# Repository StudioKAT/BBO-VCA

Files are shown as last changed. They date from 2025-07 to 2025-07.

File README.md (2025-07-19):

# BBO&VCA
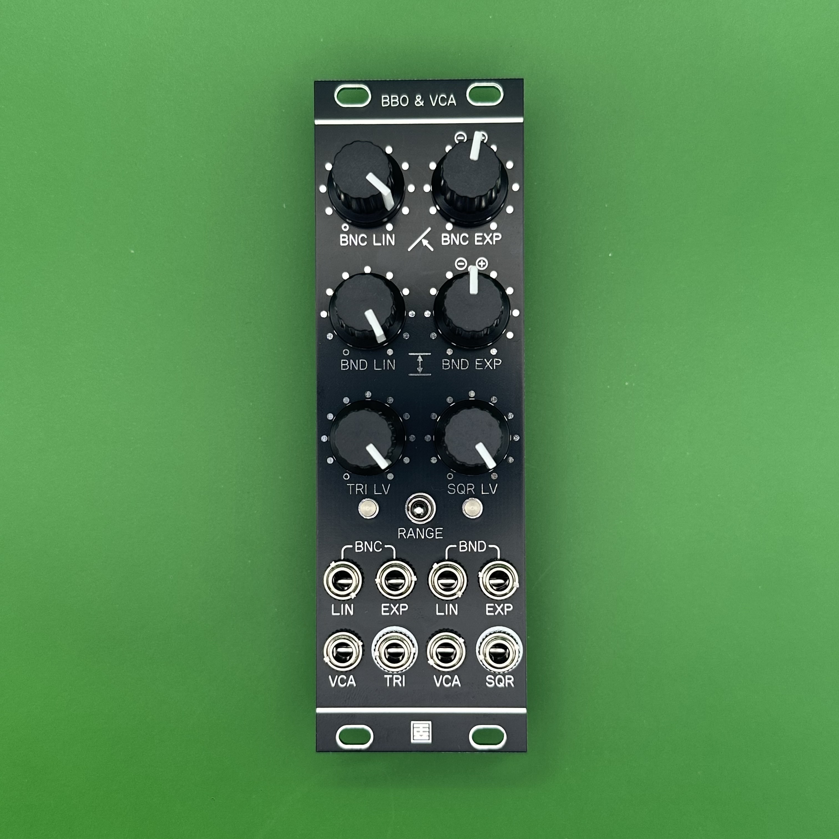
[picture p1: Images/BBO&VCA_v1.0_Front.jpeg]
BBO&VCA_Front


## 概要 / Overview

**BBO&VCA** は、Ieaskul F. Mobenthey の Denum と [crucFX Utility BBO](https://github.com/d42kn355/BoundsBounceOscillator) にインスパイアされた「バウンズ・バウンス・オシレーター（Bounds Bounce Oscillator）」です。  
この回路は、「バウンス（Bounce）」と「バウンズ（Bounds）」という、2つの概念を軸に動作します。  
ボールが2つの壁の間を行き来して跳ねている様子をイメージしてください。バウンスはボールのスピード、バウンズはその2つの壁の距離です。  
このオシレーターでは、バウンスを大きくすると周波数が上がり、バウンズを狭めると振幅が下がる代わりに周波数はさらに上がります。つまり、壁を近づけると、ボール（信号）の移動が速くなるという構造です。  
**BBO&VCA** は、バウンスとバウンズをそれぞれ独立して調整・変調でき、主出力からは常に三角波が出力されます。また、もう1つの出力からは矩形波が得られます。  
さらに、レンジスイッチにより3つの動作範囲を選択できます：
- 標準オーディオレート
- 低オーディオレート
- LFOレート

出力される三角波と矩形波は、それぞれ専用のリニアVCAを通して出力されており、外部CVやノブで音量（振幅）をコントロールできます。  
> ※ 1V/oct の標準CVピッチ制御には対応していません。

**BBO&VCA** is a "Bounds Bounce Oscillator" inspired by Ieaskul F. Mobenthey's *Denum* and the [crucFX Utility BBO](https://github.com/d42kn355/BoundsBounceOscillator).  
This circuit operates based on two key concepts: **Bounce** and **Bounds**.  
Imagine a ball bouncing back and forth between two walls. The **Bounce** represents the speed of the ball, and the **Bounds** represent the distance between the two walls.  

In this oscillator, increasing the Bounce raises the frequency. Narrowing the Bounds further increases the frequency but reduces the amplitude.  
In other words, when the walls are brought closer together, the ball (i.e., the signal) travels faster, resulting in a higher pitch.

**BBO&VCA** allows independent control and modulation of both Bounce and Bounds.  
The main output always produces a triangle wave, while the secondary output provides a square wave.  

A range switch allows you to select from three operating ranges:
- Standard audio rate  
- Low audio rate  
- LFO rate  

Both the triangle and square waves are routed through dedicated linear VCAs, allowing you to control their amplitude (volume) via knobs or external CV.

> *Note: This module does not support standard 1V/oct pitch tracking.*

## 仕様 / Spec
- Format: Eurorack
- Function: Oscillator / LFO
- Current needs: +12V: 30mA, -12V: 30mA
- Width: 8 HP
- Depth: 25mm (including power connector)

## 販売 / Sales

StudioKATオフィシャルショップで販売しています。(日本国内限定)  
 https://www.studiokat.jp/items/113562094

## ライセンス / License

この作品は [Creative Commons 表示 - 継承 4.0 国際 (CC BY-SA 4.0)](https://creativecommons.org/licenses/by-sa/4.0/deed.ja) の下でライセンスされています。  
This work is licensed under the [Creative Commons Attribution-ShareAlike 4.0 International License](https://creativecommons.org/licenses/by-sa/4.0/).

## クレジット / Credits

- Designed by : StudioKAT
- Website : https://www.studiokat.jp/
- GitHub : https://github.com/StudioKAT
- X(Twitter) : https://x.com/StudioKAT_synth
- Instagram : https://www.instagram.com/studiokat_modular/

## 更新履歴 / Changelog

- `2025-07-17` Released version 1.0

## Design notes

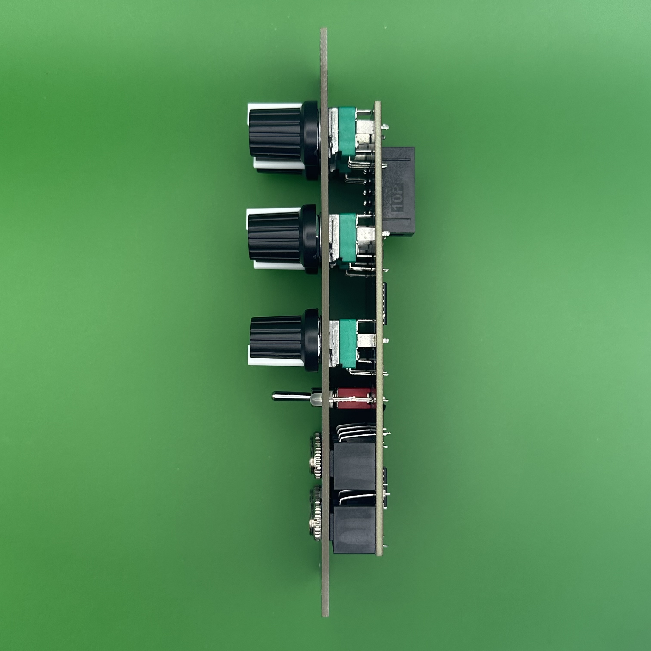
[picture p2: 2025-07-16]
Images/BBO&VCA_v1.0_Side.jpeg

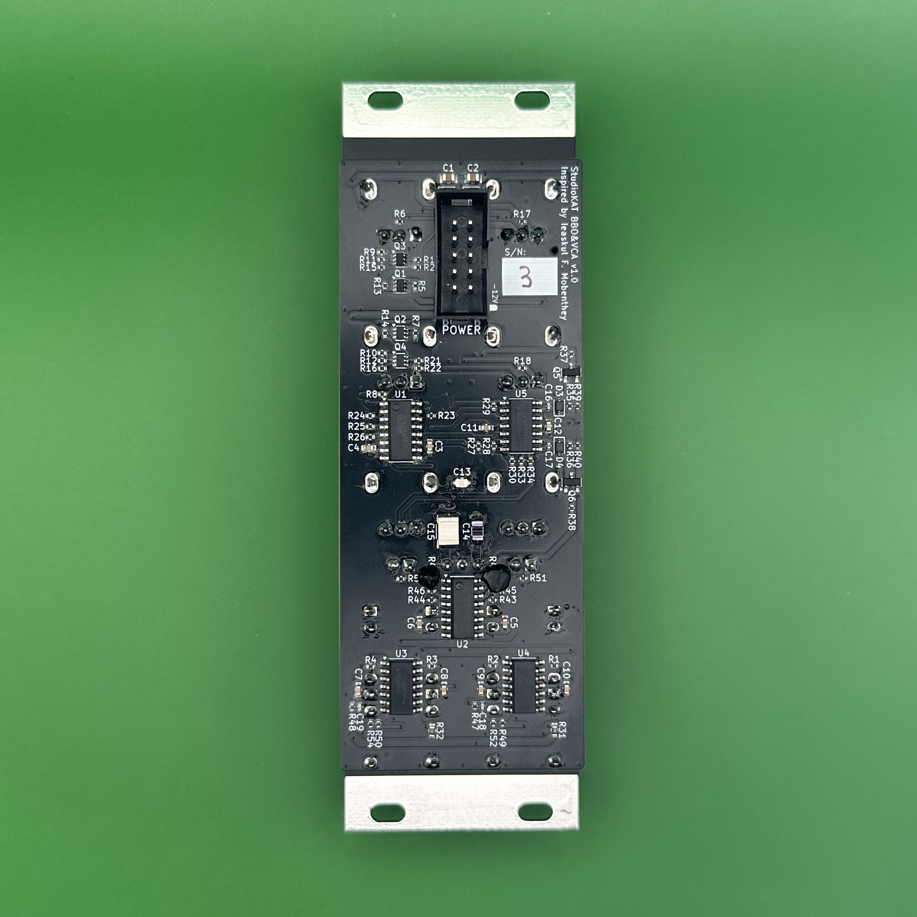
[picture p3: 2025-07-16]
Images/BBO&VCA_v1.0_Back.jpeg

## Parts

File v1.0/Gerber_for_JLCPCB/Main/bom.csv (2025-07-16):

Designator | Footprint | Quantity | Value | LCSC Part #
C1, C2 | 0805 | 2 | 22uF | C45783
C10, C11, C12, C3, C4, C5, C6, C7, C8, C9 | 0603 | 10 | 100nF | C14663
C13 | 0805 | 1 | 1nF
C14 | 1206 | 1 | 1uF
C15 | 1913 | 1 | 47nF
C16, C17 | 0402 | 2 | 330pF | C13533
C18, C19 | 0402 | 2 | 47pF | C1567
D1, D2 | D_SOD-323 | 2 | 1N5819WS | C64886
D3, D4 | D_SOD-323 | 2 | 1N4148WS | C2128
D5, D6 | LED_D3.0mm | 2 | LED_Dual_Bidirectional
J1 | BoxHeader_2x05_2.54mm_Europower_2 | 1 | POWER
J2 | AudioJack_PJ301M-12 | 1 | Bounce_Lin
J3 | AudioJack_PJ301M-12 | 1 | Bounce_CV
J4 | AudioJack_PJ301M-12 | 1 | Bounds_Lin
J5 | AudioJack_PJ301M-12 | 1 | Bounds_CV
J6 | AudioJack_PJ301M-12 | 1 | VCA_CV_Triangle
J7 | AudioJack_PJ301M-12 | 1 | VCA_CV_Square
J8 | AudioJack_PJ301M-12 | 1 | Triangle_OUT
J9 | AudioJack_PJ301M-12 | 1 | Square_OUT
Q1, Q2, Q3, Q4 | SOT-363_SC-70-6 | 4 | BCM857BS | C20426291
Q5, Q6 | SOT-23 | 2 | MMBT3906 | C7420354
R1, R2, R3, R4 | 0402 | 4 | 10M | C26082
R10, R19, R21, R6, R8, R9 | 0402 | 6 | 100K | C25741
R11, R12, R20, R22, R26, R29, R30, R49, R50 | 0402 | 9 | 10K | C25744
R13, R14, R15, R16, R51, R53 | 0402 | 6 | 4.7K | C25900
R17, R18, R24, R25 | 0402 | 4 | 47K | C25792
R23 | 0402 | 1 | 470K | C25790
R27, R28, R5, R7 | 0402 | 4 | 22K | C25768
R31, R32 | 0603 | 2 | 15K | C22809
R33, R34 | 0402 | 2 | 330K | C25778
R35, R36 | 0402 | 2 | 33K | C25779
R37, R38 | 0402 | 2 | 6.8K | C25917
R39, R40, R52, R54 | 0402 | 4 | 1K | C11702
R41 | 0603 | 1 | 240K | C4197
R42 | 0603 | 1 | 360K | C23146
R43, R44, R45, R46 | 0402 | 4 | 680R | C25130
R47, R48 | 0402 | 2 | 18K | C25762
RV1, RV2, RV3, RV4 | Potentiometer_RV09 | 4 | B50K
RV5, RV6 | Potentiometer_RV09 | 2 | B100K
SW1 | ToggleSwitch_2MS1-T2-B4-M2-Q-E-S | 1 | SW_SPDT_MSM
U1, U2 | SOIC-16_3.9x9.9mm_P1.27mm | 2 | LM13700 | C174050
U3, U4, U5 | SOIC-14_3.9x8.7mm_P1.27mm | 3 | TL074 | C12594

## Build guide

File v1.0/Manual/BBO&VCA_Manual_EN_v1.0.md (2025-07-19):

# BBO&VCA Manual (EN)
BBO&VCA_Front

## Overview

**BBO&VCA** is a "Bounds Bounce Oscillator" inspired by Ieaskul F. Mobenthey’s *Denum* and the [crucFX Utility BBO](https://github.com/d42kn355/BoundsBounceOscillator).  
This oscillator is based on two key concepts: **Bounce** and **Bounds**.  
Imagine a ball bouncing back and forth between two walls. The **Bounce** represents the speed of the ball, and the **Bounds** represent the distance between the walls.  
In this oscillator, increasing the Bounce raises the frequency, while narrowing the Bounds increases the frequency further but reduces the amplitude. In other words, bringing the walls closer causes the ball (signal) to move faster.

**BBO&VCA** allows you to independently adjust and modulate both Bounce and Bounds. The main output always provides a triangle wave, while a secondary output provides a square wave.  
A range switch offers three operating modes:
- Standard audio rate  
- Low audio rate  
- LFO rate

Both the triangle and square waves are passed through dedicated linear VCAs, allowing their amplitude (volume) to be controlled via knobs or external CV.

## Specifications

- **Format**: Eurorack  
- **Width**: 8 HP  
- **Depth**: 25 mm  
- **Current Consumption**: +12V: 30mA / -12V: 30mA  

> **IMPORTANT**: Connect the ribbon cable so that the red stripe aligns with -12V.  
> Incorrect connection may damage the module.  
> **Always check cable orientation before powering on.**

## Functions of Each Section
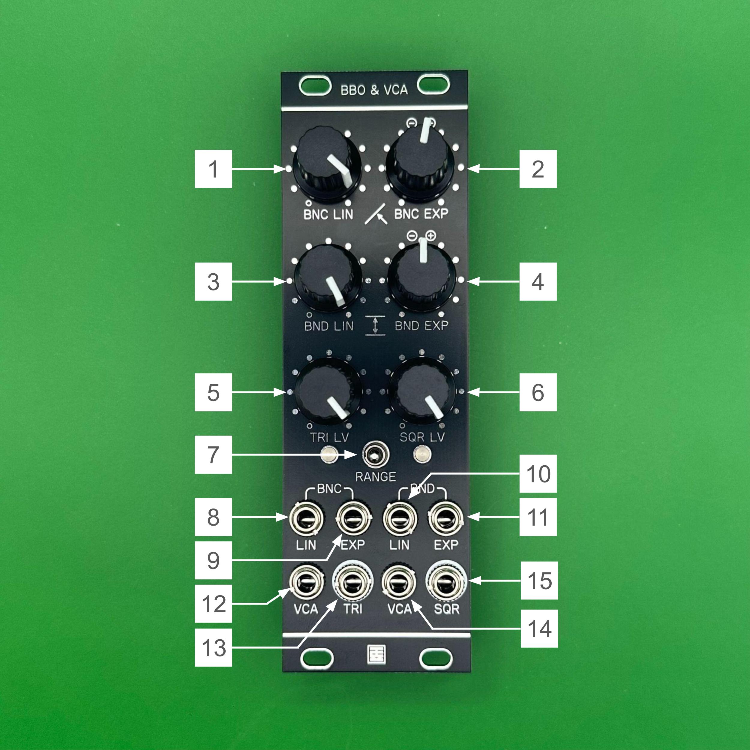
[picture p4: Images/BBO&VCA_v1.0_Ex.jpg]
BBO&VCA_Explanation


1. **BNC LIN**  
   Sets the base position and speed (rate) for Bounce.

2. **BNC EXP**  
   Attenuverter for the CV signal connected to BNC EXP IN. At the center position, modulation is off. Turning clockwise applies modulation with positive polarity, and counterclockwise applies it with inverted polarity.

3. **BND LIN**  
   Sets the base position and speed (rate) for Bounds.

4. **BND EXP**  
   Attenuverter for the CV signal connected to BND EXP IN. At the center position, modulation is off. Turning clockwise applies modulation with positive polarity, and counterclockwise applies it with inverted polarity.

5. **TRI LV**  
   Adjusts the amplitude (volume) of the triangle wave.

6. **SQR LV**  
   Adjusts the amplitude (volume) of the square wave.

7. **RANGE**  
   Switch to select oscillator range. Three options available:  
   - Standard audio rate  
   - Low audio rate  
   - LFO rate

8. **BNC LIN IN**  
   Linear CV input for Bounce.

9. **BNC EXP IN**  
   Exponential CV input for Bounce.

10. **BND LIN IN**  
   Linear CV input for Bounds.

11. **BND EXP IN**  
   Exponential CV input for Bounds.

12. **TRI VCA IN**  
   CV input for triangle wave amplitude control.

13. **TRI OUT**  
   Triangle wave output.

14. **SQR VCA IN**  
   CV input for square wave amplitude control.

15. **SQR OUT**  
   Square wave output.

> *This module does not support standard 1V/oct pitch tracking.*

## License

This work is licensed under the [Creative Commons Attribution-ShareAlike 4.0 International (CC BY-SA 4.0)](https://creativecommons.org/licenses/by-sa/4.0/deed.en).

## Credits

- **Designed by**: StudioKAT  
- **Website**: [https://www.studiokat.jp/](https://www.studiokat.jp/)  
- **GitHub**: [https://github.com/StudioKAT](https://github.com/StudioKAT)  
- **X (formerly Twitter)**: [https://x.com/StudioKAT_synth](https://x.com/StudioKAT_synth)  
- **Instagram**: [https://www.instagram.com/studiokat_modular/](https://www.instagram.com/studiokat_modular/)

## Revision History

- `2025-07-17`: v1.0 Release

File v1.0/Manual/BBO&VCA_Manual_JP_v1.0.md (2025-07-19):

# BBO&VCA マニュアル（日本語）
BBO&VCA_Front

## 概要

**BBO&VCA** は、Ieaskul F. Mobenthey の Denum と [crucFX Utility BBO](https://github.com/d42kn355/BoundsBounceOscillator) にインスパイアされた「バウンズ・バウンス・オシレーター（Bounds Bounce Oscillator）」です。  
この回路は、「バウンス（Bounce）」と「バウンズ（Bounds）」という、2つの概念を軸に動作します。  
ボールが2つの壁の間を行き来して跳ねている様子をイメージしてください。バウンスはボールのスピード、バウンズはその2つの壁の距離です。  
このオシレーターでは、バウンスを大きくすると周波数が上がり、バウンズを狭めると振幅が下がる代わりに周波数はさらに上がります。つまり、壁を近づけると、ボール（信号）の移動が速くなるという構造です。  
**BBO&VCA** は、バウンスとバウンズをそれぞれ独立して調整・変調でき、主出力からは常に三角波が出力されます。また、もう1つの出力からは矩形波が得られます。  
さらに、レンジスイッチにより3つの動作範囲を選択できます：
- 標準オーディオレート
- 低オーディオレート
- LFOレート

出力される三角波と矩形波は、それぞれ専用のリニアVCAを通して出力されており、外部CVやノブで音量（振幅）をコントロールできます。  

## 仕様

- **フォーマット**：Eurorack  
- **幅**：8 HP  
- **奥行き**：25 mm  
- **消費電流**：+12V: 30mA / -12V: 30mA  

> ※ ケーブルの赤いラインが -12V に接続されるようにしてください。  
> 誤って接続すると、モジュールが故障する可能性があります。  
> **電源投入前にケーブルの向きを必ず確認してください。**

## 各部の機能
BBO&VCA_Explanation

1. **BNC LIN**  
   バウンス（Bounce）の基準位置や速度（レート）を設定するノブです。

2. **BNC EXP**  
   BNC EXP IN に接続されたCV信号の影響度を調整するアッテヌバーターです。ノブ中央で無効、時計回りで正極性、反時計回りで逆極性のモジュレーションが適用されます。

3. **BND LIN**  
   バウンズ（Bounds）の基準位置や速度（レート）を設定するノブです。

4. **BND EXP**  
   BND EXP IN に接続されたCV信号の影響度を調整するアッテヌバーターです。ノブ中央で無効、時計回りで正極性、反時計回りで逆極性のモジュレーションが適用されます。

5. **TRI LV**  
   三角波の音量（振幅）を調整するノブです。

6. **SQR LV**  
   矩形波の音量（振幅）を調整するノブです。

7. **RANGE**  
   発振レンジを切り替えるスイッチです。以下の3段階があります：  
   - 標準オーディオレート  
   - 低オーディオレート  
   - LFOレート

8. **BNC LIN IN**  
   バウンス（Bounce）のリニアCV入力です。

9. **BNC EXP IN**  
   バウンス（Bounce）のエクスポネンシャルCV入力です。

10. **BND LIN IN**  
   バウンズ（Bounds）のリニアCV入力です。

11. **BND EXP IN**  
   バウンズ（Bounds）のエクスポネンシャルCV入力です。

12. **TRI VCA IN**  
   三角波の音量を制御するためのCV入力です。

13. **TRI OUT**  
   三角波の出力端子です。

14. **SQR VCA IN**  
   矩形波の音量を制御するためのCV入力です。

15. **SQR OUT**  
   矩形波の出力端子です。

> ※ 本モジュールは 1V/oct の標準CVピッチ制御には対応していません。

## ライセンス

この作品は [Creative Commons 表示 - 継承 4.0 国際 (CC BY-SA 4.0)](https://creativecommons.org/licenses/by-sa/4.0/deed.ja) の下でライセンスされています。

## クレジット

- **Designed by**：StudioKAT  
- **Website**：[https://www.studiokat.jp/](https://www.studiokat.jp/)  
- **GitHub**：[https://github.com/StudioKAT](https://github.com/StudioKAT)  
- **X（旧Twitter）**：[https://x.com/StudioKAT_synth](https://x.com/StudioKAT_synth)  
- **Instagram**：[https://www.instagram.com/studiokat_modular/](https://www.instagram.com/studiokat_modular/)

## 更新履歴

- `2025-07-17`：v1.0 リリース

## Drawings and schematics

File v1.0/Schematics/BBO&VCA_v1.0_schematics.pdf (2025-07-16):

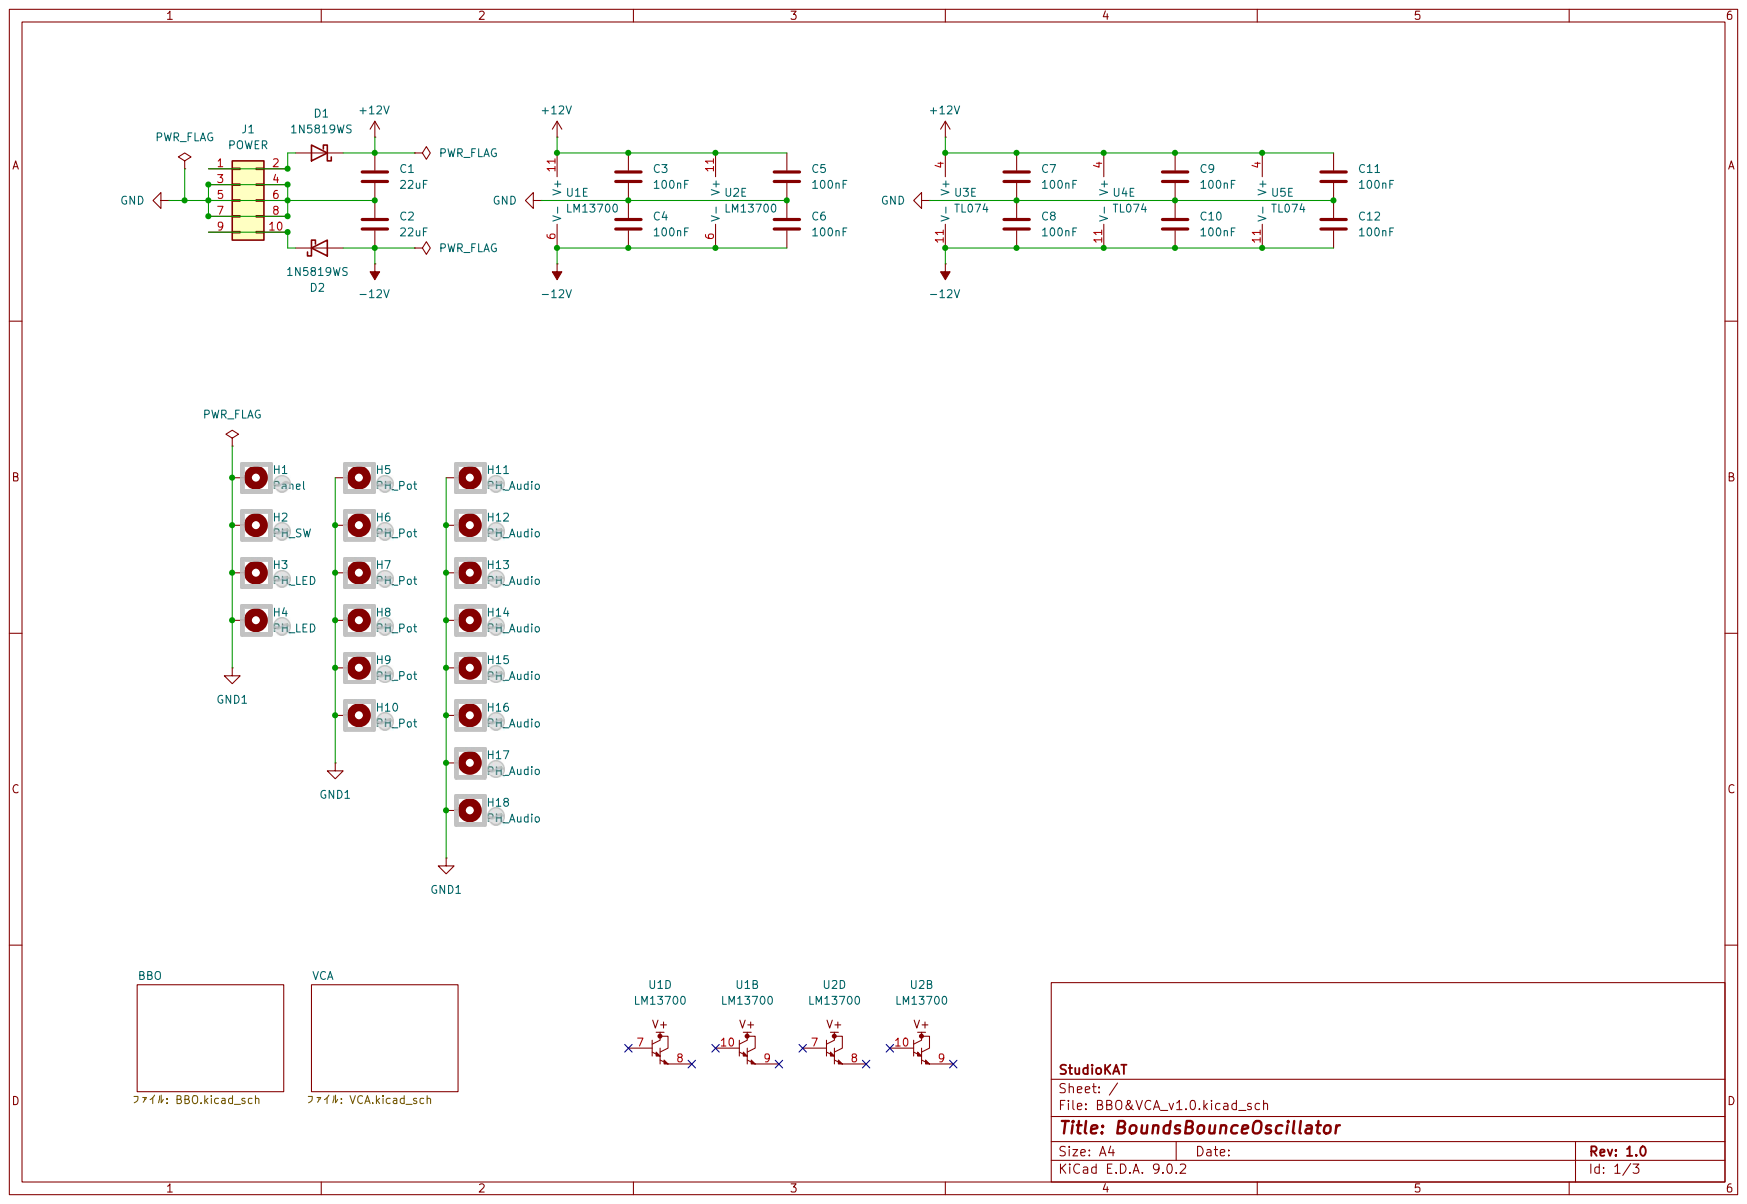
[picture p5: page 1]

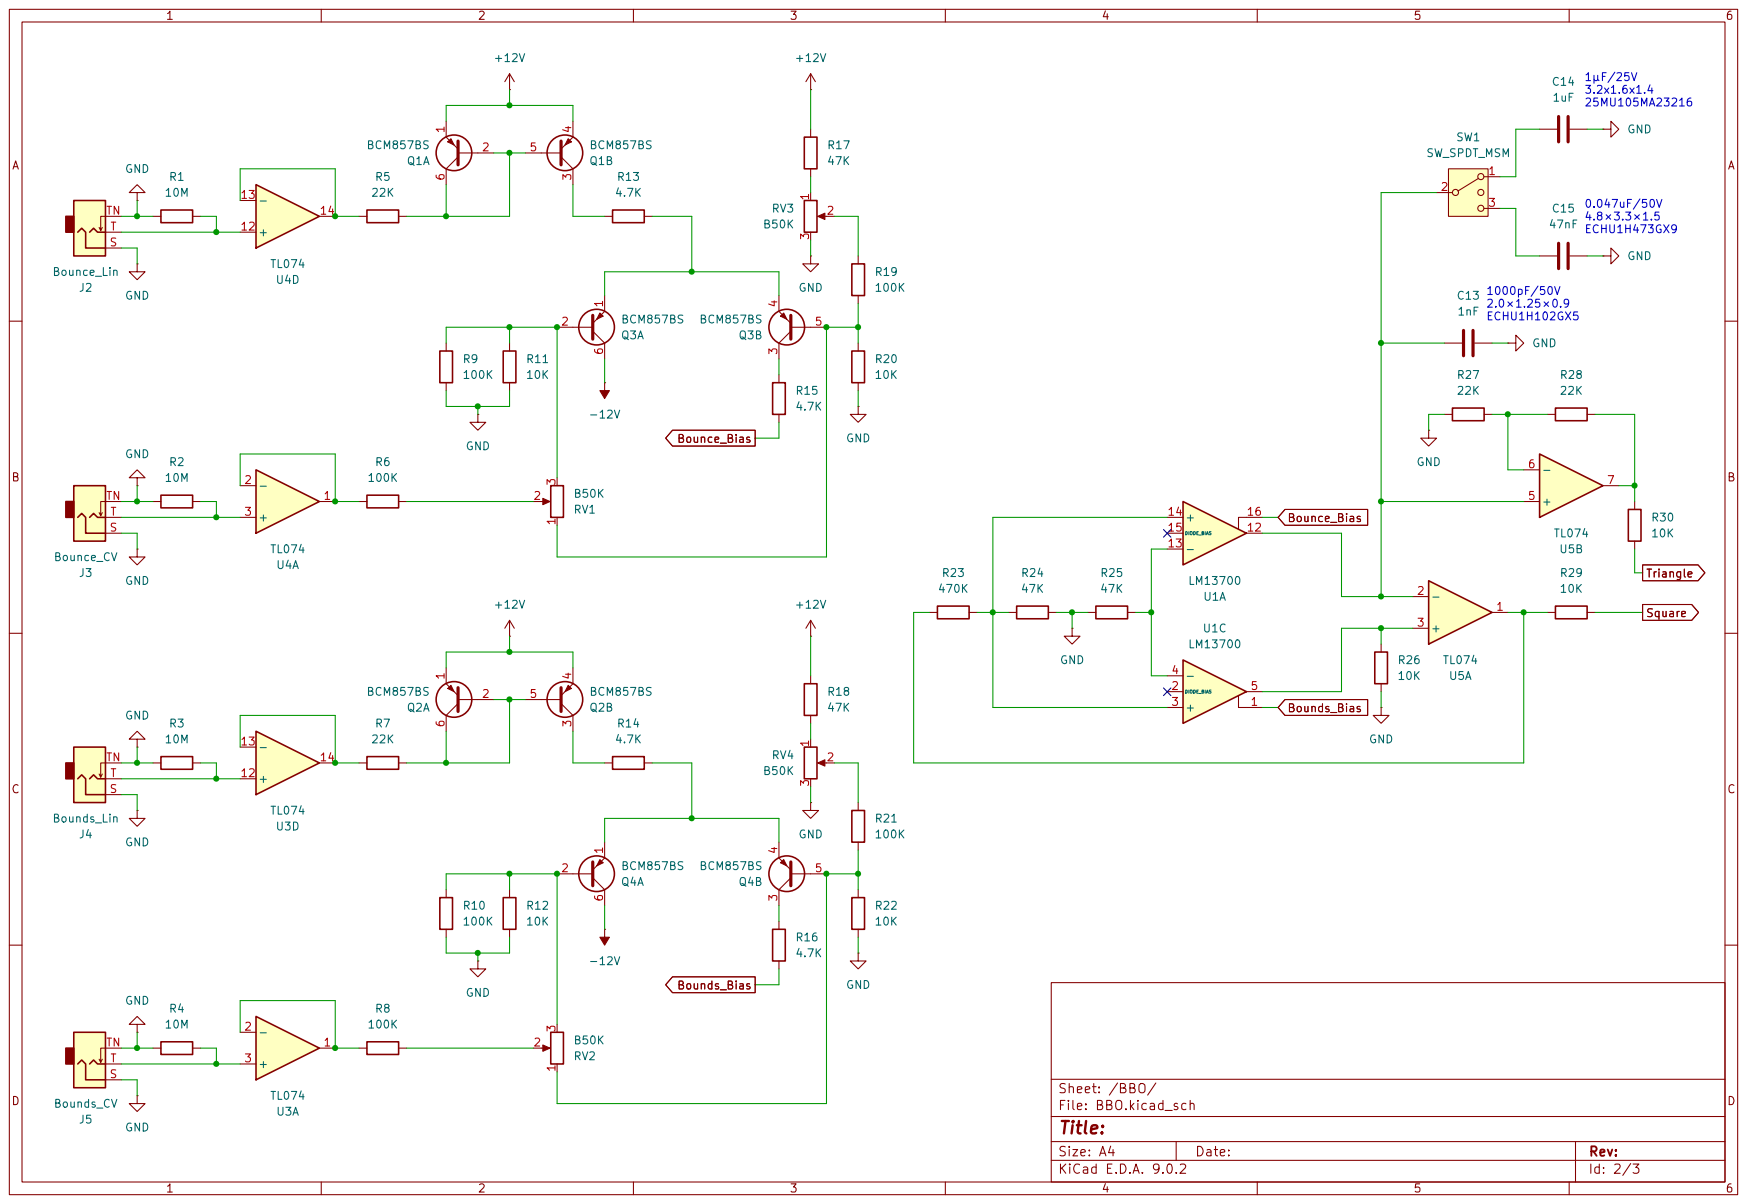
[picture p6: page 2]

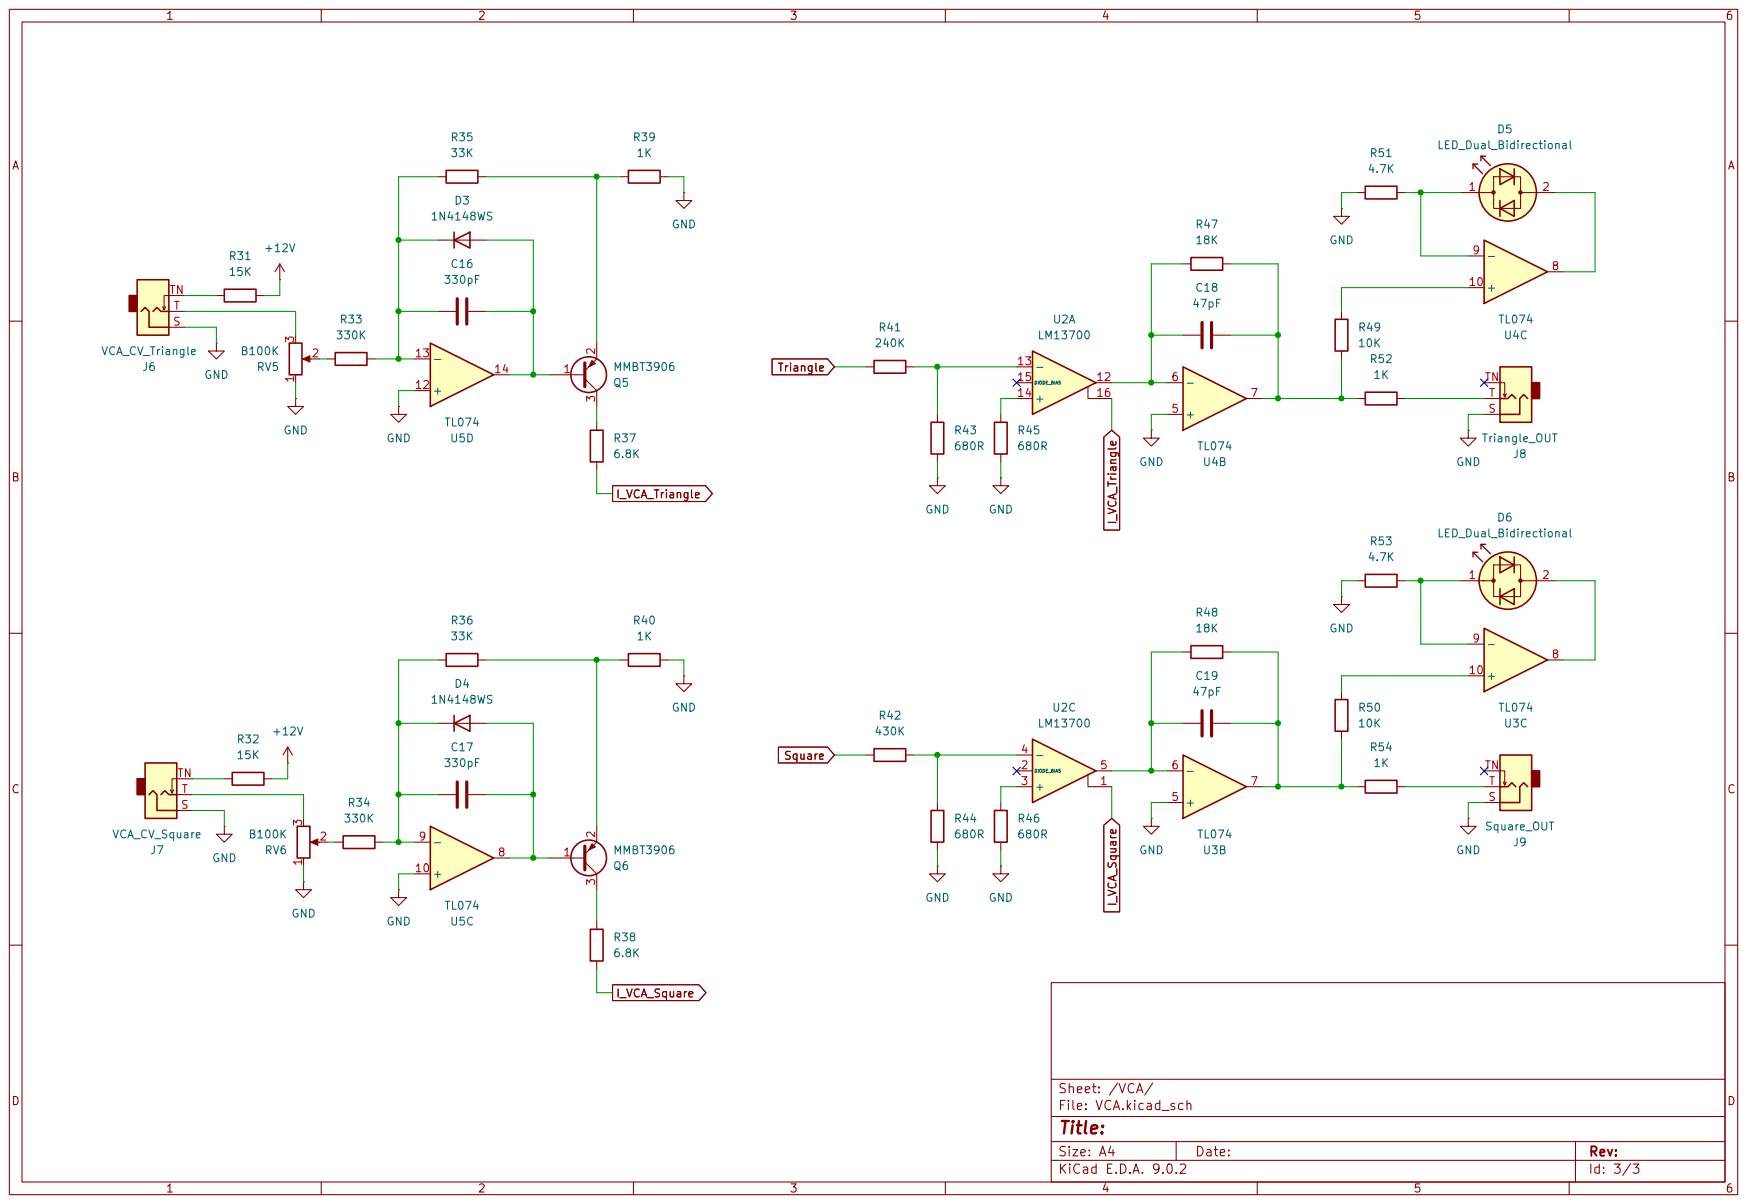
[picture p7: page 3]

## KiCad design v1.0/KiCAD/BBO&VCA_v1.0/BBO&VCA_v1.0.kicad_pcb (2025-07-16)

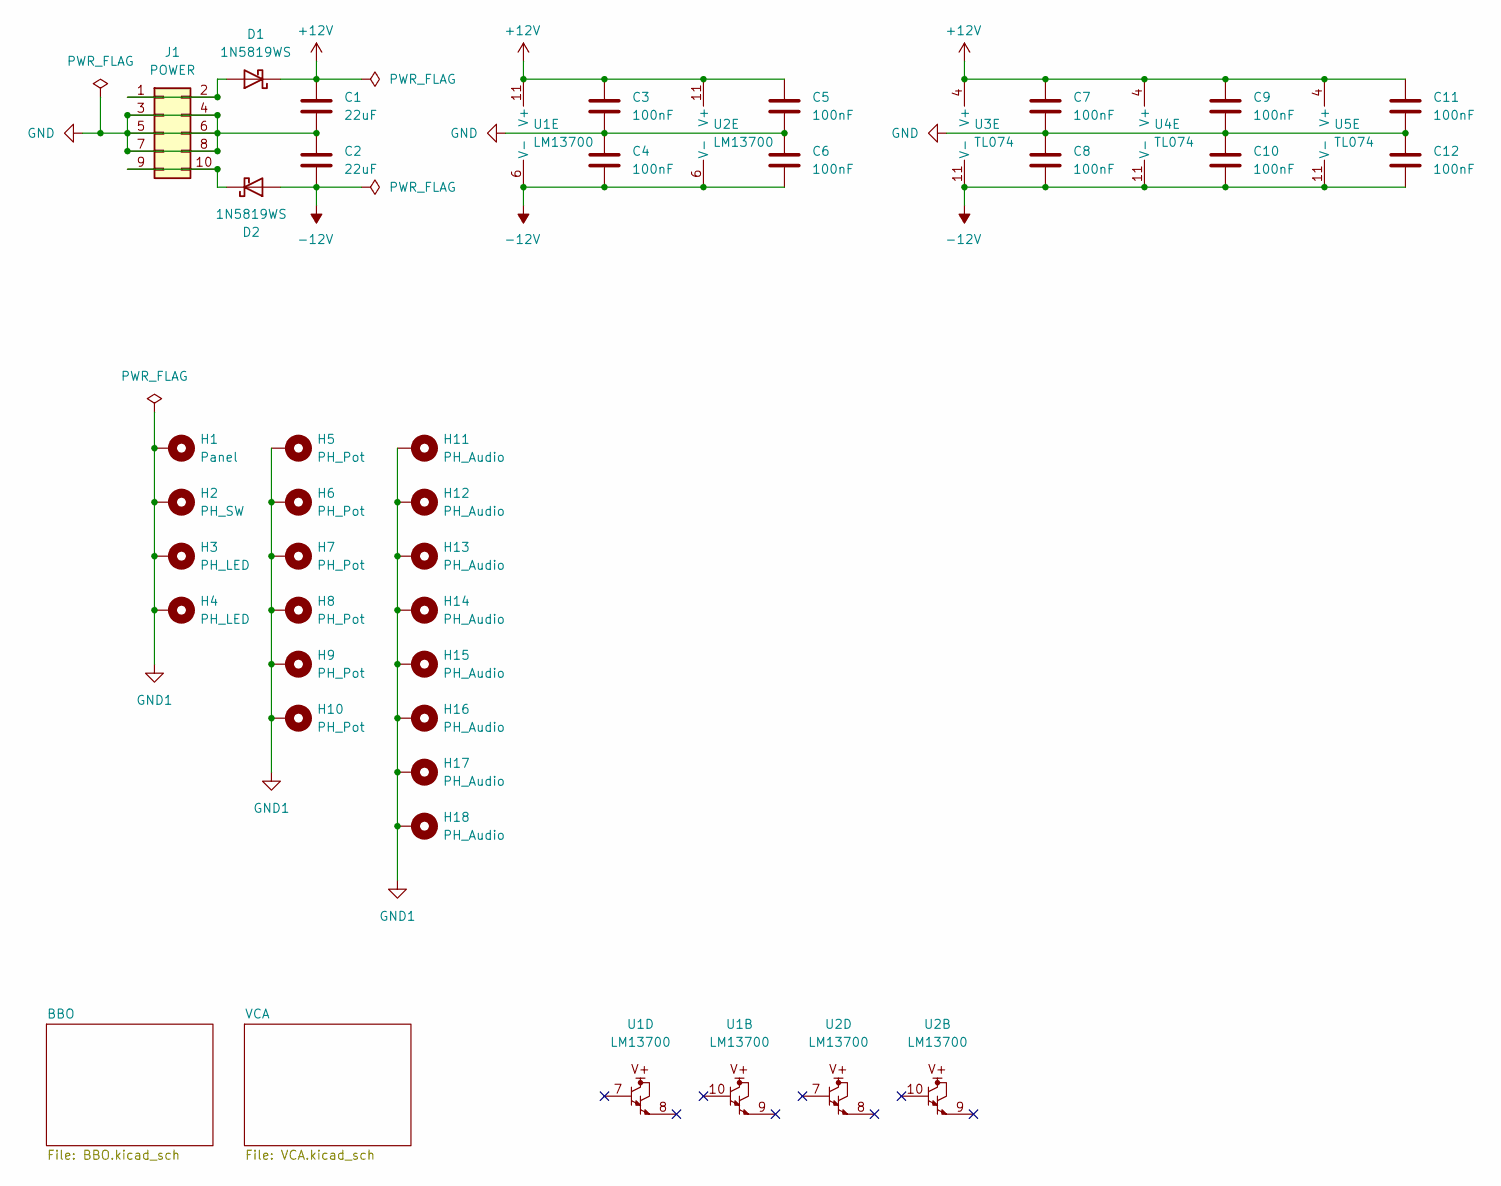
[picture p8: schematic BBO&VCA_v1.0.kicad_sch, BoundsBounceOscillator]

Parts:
C1, C2: 22uF; C_0805_2012Metric; LCSC C45783
C3, C4, C5, C6, C7, C8, C9, C10, C11, C12: 100nF; C_0603_1608Metric; LCSC C14663
D1, D2: 1N5819WS; D_SOD-323; LCSC C64886
H1: Panel; Panel_8HP
H2: PH_SW; PH_ToggleSwitch_5.1mm_Pad
H3, H4: PH_LED; PH_LED_3.0mm_Pad
H5, H6, H9, H10: PH_Pot; PH_RK097_15mmKnob_Pad
H7, H8: PH_Pot; PH_RK097_15mmKnob_Uni_Pad
H11, H12, H13, H14, H15, H16, H17, H18: PH_Audio; PH_AudioJack_3.5mm_Pad
J1: POWER; BoxHeader_2x05_2.54mm_Europower_2
U1, U2: LM13700; SOIC-16_3.9x9.9mm_P1.27mm; LCSC C174050
U3, U4, U5: TL074; SOIC-14_3.9x8.7mm_P1.27mm; LCSC C12594

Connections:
+12V: C1.1, C3.1, C5.1, C7.1, C9.1, C11.1, D1.1 (K), U1.11 (V+), U2.11 (V+), U3.4 (V+), U4.4 (V+), U5.4 (V+); also elsewhere on the board
-12V: C2.2, C4.2, C6.2, C8.2, C10.2, C12.2, D2.2 (A), U1.6 (V-), U2.6 (V-), U3.11 (V-), U4.11 (V-), U5.11 (V-); also elsewhere on the board
GND: C1.2, C2.1, C3.2, C4.1, C5.2, C6.1, C7.2, C8.1, C9.2, C10.1, C11.2, C12.1, J1.3, J1.4, J1.5, J1.6, J1.7, J1.8; also elsewhere on the board
GND1: H1.1, H2.1, H3.1, H4.1, H5.1, H6.1, H7.1, H8.1, H9.1, H10.1, H11.1, H12.1, H13.1, H14.1, H15.1, H16.1, H17.1, H18.1
unnamed: D1.2 (A), J1.1, J1.2
unnamed: D2.1 (K), J1.9, J1.10

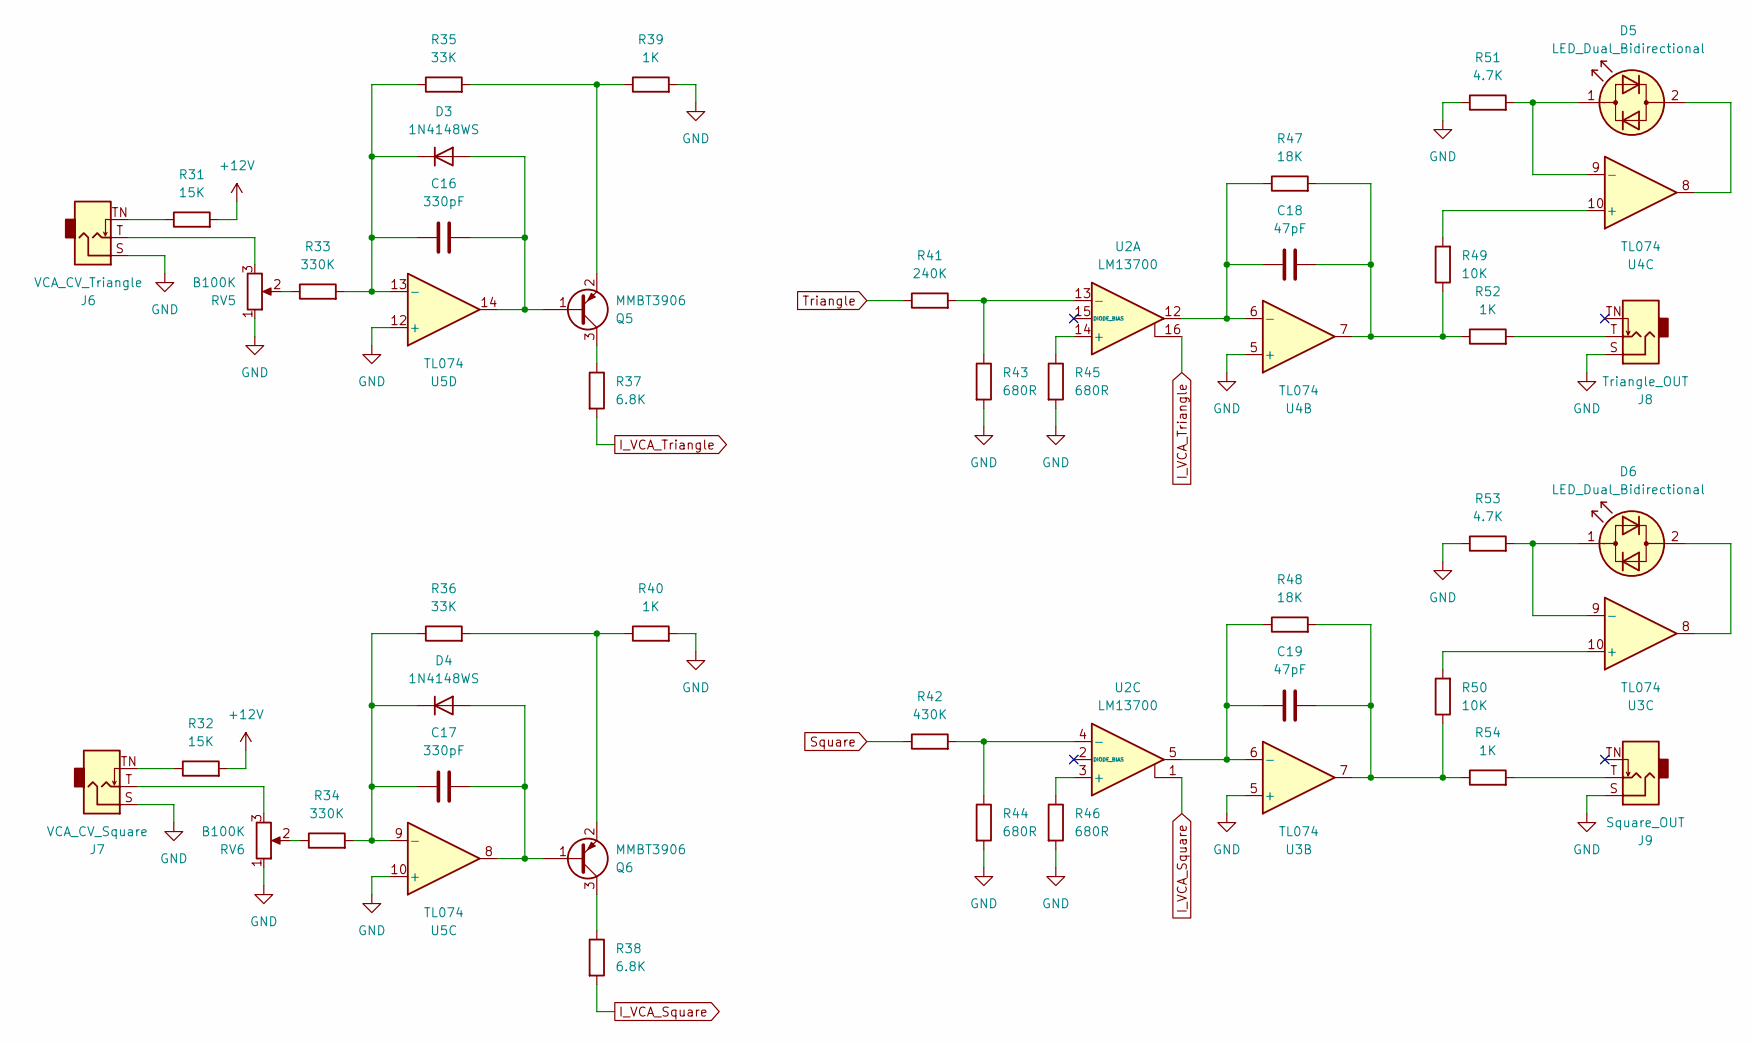
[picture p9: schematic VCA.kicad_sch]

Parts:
C16, C17: 330pF; C_0402_1005Metric; LCSC C13533
C18, C19: 47pF; C_0402_1005Metric; LCSC C1567
D3, D4: 1N4148WS; D_SOD-323; LCSC C2128
D5, D6: LED_Dual_Bidirectional; LED_D3.0mm
J6: VCA_CV_Triangle; AudioJack_PJ301M-12
J7: VCA_CV_Square; AudioJack_PJ301M-12
J8: Triangle_OUT; AudioJack_PJ301M-12
J9: Square_OUT; AudioJack_PJ301M-12
Q5, Q6: MMBT3906; SOT-23; LCSC C7420354
R31, R32: 15K; R_0603_1608Metric; LCSC C22809
R33, R34: 330K; R_0402_1005Metric; LCSC C25778
R35, R36: 33K; R_0402_1005Metric; LCSC C25779
R37, R38: 6.8K; R_0402_1005Metric; LCSC C25917
R39, R40, R52, R54: 1K; R_0402_1005Metric; LCSC C11702
R41: 240K; R_0603_1608Metric; LCSC C4197
R42: 430K; R_0603_1608Metric; LCSC C25969
R43, R44, R45, R46: 680R; R_0402_1005Metric; LCSC C25130
R47, R48: 18K; R_0402_1005Metric; LCSC C25762
R49, R50: 10K; R_0402_1005Metric; LCSC C25744
R51, R53: 4.7K; R_0402_1005Metric; LCSC C25900
RV5, RV6: B100K; Potentiometer_RV09
U2: LM13700; SOIC-16_3.9x9.9mm_P1.27mm; LCSC C174050
U3, U4, U5: TL074; SOIC-14_3.9x8.7mm_P1.27mm; LCSC C12594

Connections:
+12V: R31.2, R32.2; also elsewhere on the board
GND: J6.S, J7.S, J8.S, J9.S, R39.2, R40.2, R43.2, R44.2, R45.2, R46.2, R51.1, R53.1, RV5.1, RV6.1, U3.5 (+), U4.5 (+), U5.10 (+), U5.12 (+); also elsewhere on the board
I_VCA_Square: R38.2, U2.1
I_VCA_Triangle: R37.2, U2.16
unnamed: C18.2, R47.2, R49.1, R52.1, U4.7
unnamed: C19.2, R48.2, R50.1, R54.1, U3.7
unnamed: C16.2, D3.2 (A), Q5.1 (B), U5.14
unnamed: C16.1, D3.1 (K), R33.2, R35.1, U5.13 (-)
unnamed: C17.2, D4.2 (A), Q6.1 (B), U5.8
unnamed: C17.1, D4.1 (K), R34.2, R36.1, U5.9 (-)
unnamed: D5.2 (AK), U4.8
unnamed: D5.1 (KA), R51.2, U4.9 (-)
unnamed: D6.2 (AK), U3.8
unnamed: D6.1 (KA), R53.2, U3.9 (-)
unnamed: J6.T, RV5.3
unnamed: J6.TN, R31.1
unnamed: J7.T, RV6.3
unnamed: J7.TN, R32.1
unnamed: J8.T, R52.2
unnamed: J9.T, R54.2
unnamed: Q5.3 (C), R37.1
unnamed: Q5.2 (E), R35.2, R39.1
unnamed: Q6.3 (C), R38.1
unnamed: Q6.2 (E), R36.2, R40.1
unnamed: R33.1, RV5.2
unnamed: R34.1, RV6.2
unnamed: R45.1, U2.14 (+)
unnamed: R41.2, R43.1, U2.13 (-)
unnamed: R46.1, U2.3 (+)
unnamed: R42.2, R44.1, U2.4 (-)
unnamed: C19.1, R48.1, U2.5, U3.6 (-)
unnamed: R50.2, U3.10 (+)
unnamed: C18.1, R47.1, U2.12, U4.6 (-)
unnamed: R49.2, U4.10 (+)
Square: R42.1; also elsewhere on the board
Triangle: R41.1; also elsewhere on the board

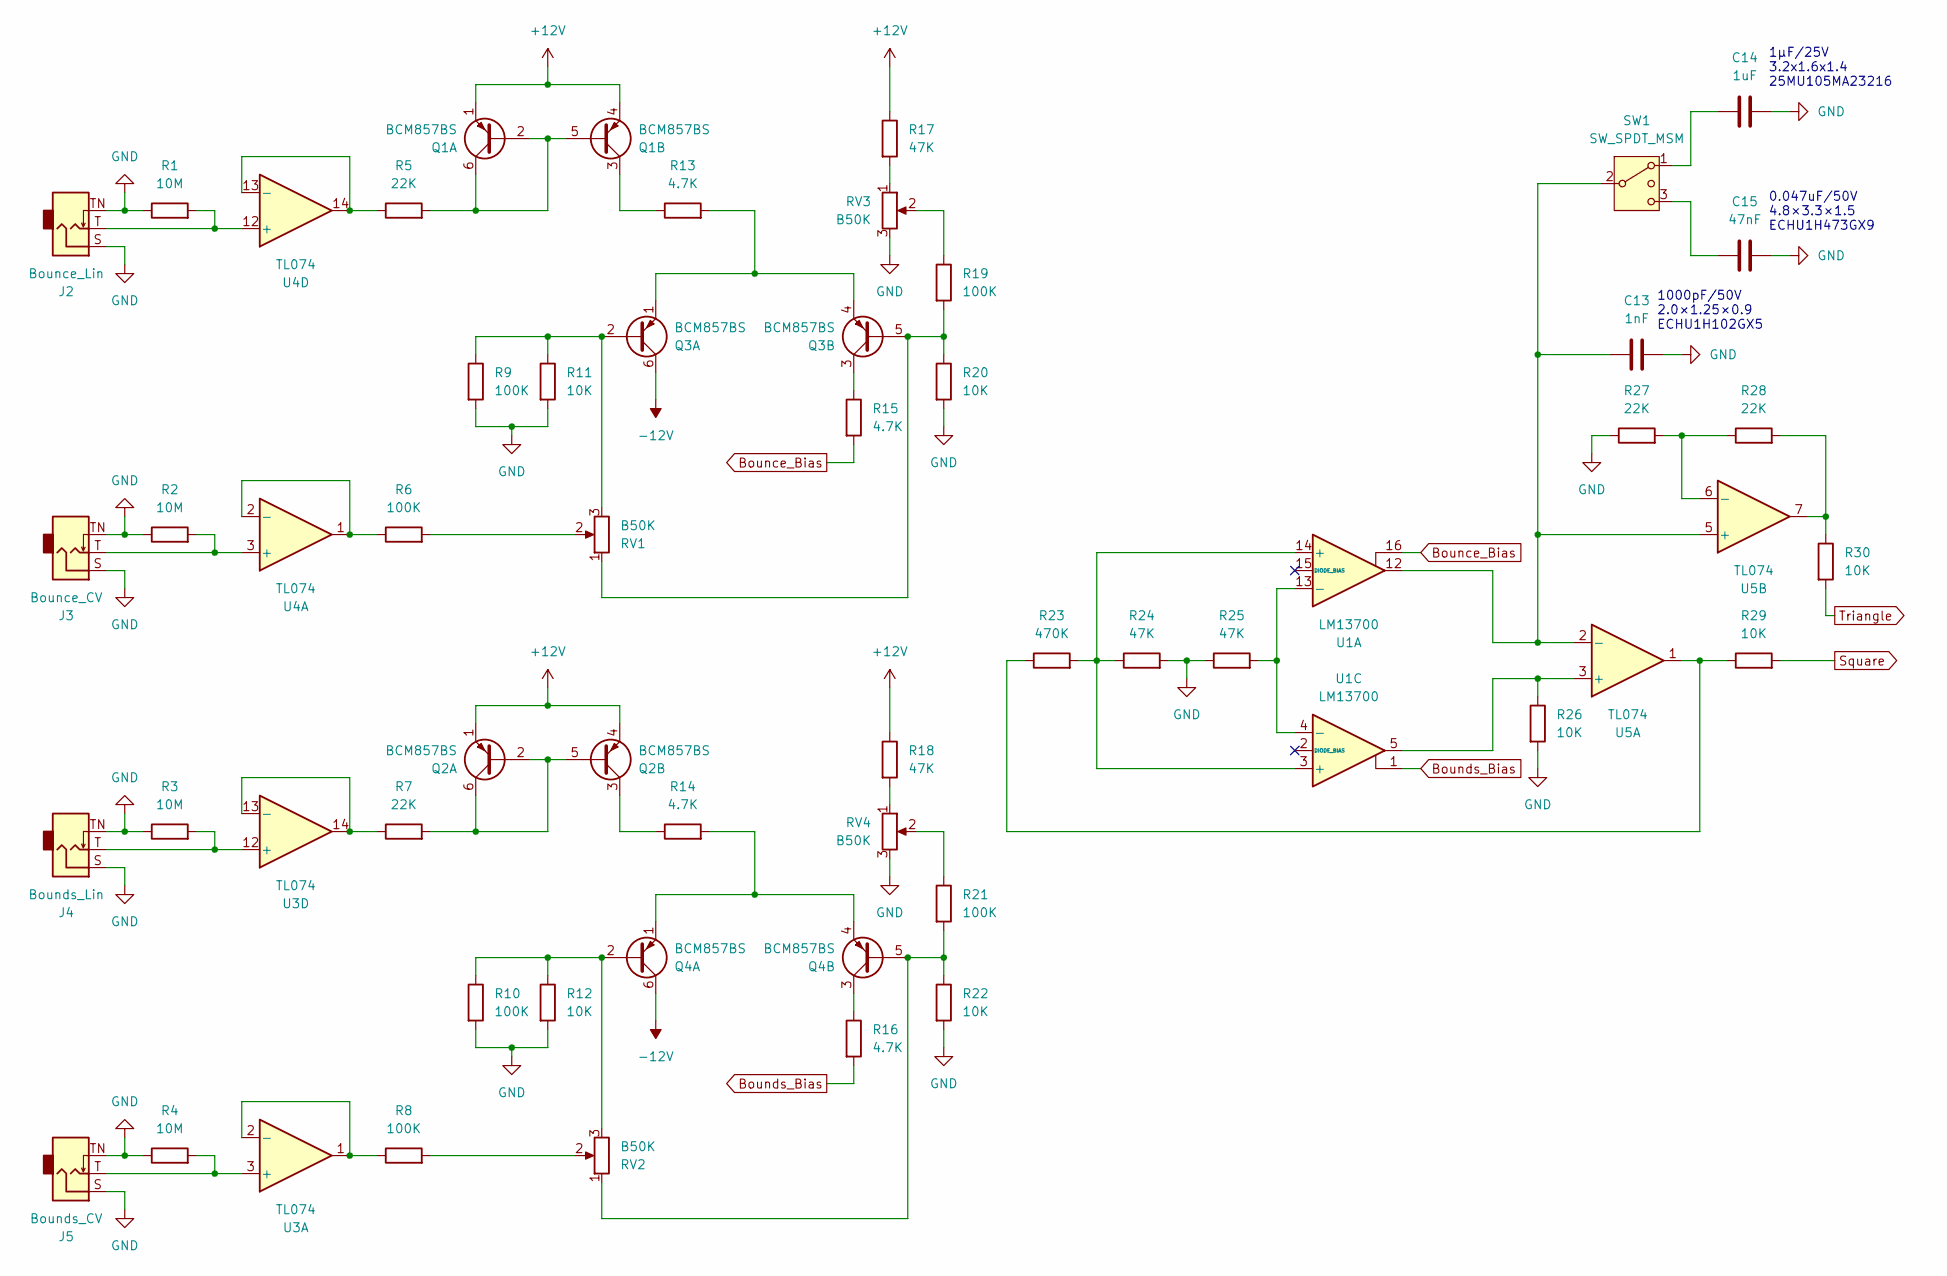
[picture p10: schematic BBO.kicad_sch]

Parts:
C13: 1nF; C_0805_2012Metric_Pad1.18x1.45mm_HandSolder
C14: 1uF; C_1206_3216Metric_Pad1.33x1.80mm_HandSolder
C15: 47nF; C_1913_4833Metric
J2: Bounce_Lin; AudioJack_PJ301M-12
J3: Bounce_CV; AudioJack_PJ301M-12
J4: Bounds_Lin; AudioJack_PJ301M-12
J5: Bounds_CV; AudioJack_PJ301M-12
Q1, Q2, Q3, Q4: BCM857BS; SOT-363_SC-70-6; LCSC C20426291
R1, R2, R3, R4: 10M; R_0402_1005Metric; LCSC C26082
R5, R7, R27, R28: 22K; R_0402_1005Metric; LCSC C25768
R6, R8, R9, R10, R19, R21: 100K; R_0402_1005Metric; LCSC C25741
R11, R12, R20, R22, R26, R29, R30: 10K; R_0402_1005Metric; LCSC C25744
R13, R14, R15, R16: 4.7K; R_0402_1005Metric; LCSC C25900
R17, R18, R24, R25: 47K; R_0402_1005Metric; LCSC C25792
R23: 470K; R_0402_1005Metric; LCSC C25790
RV1, RV2, RV3, RV4: B50K; Potentiometer_RV09
SW1: SW_SPDT_MSM; ToggleSwitch_2MS1-T2-B4-M2-Q-E-S
U1: LM13700; SOIC-16_3.9x9.9mm_P1.27mm; LCSC C174050
U3, U4, U5: TL074; SOIC-14_3.9x8.7mm_P1.27mm; LCSC C12594

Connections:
+12V: Q1.1 (E1), Q1.4 (E2), Q2.1 (E1), Q2.4 (E2), R17.1, R18.1; also elsewhere on the board
-12V: Q3.6 (C1), Q4.6 (C1); also elsewhere on the board
Bounce_Bias: R15.2, U1.16
Bounds_Bias: R16.2, U1.1
GND: C13.2, C14.2, C15.2, J2.S, J2.TN, J3.S, J3.TN, J4.S, J4.TN, J5.S, J5.TN, R1.1, R2.1, R3.1, R4.1, R9.2, R10.2, R11.2, R12.2, R20.2, R22.2, R24.2, R25.1, R26.2, R27.1, RV3.3, RV4.3; also elsewhere on the board
unnamed: C14.1, SW1.1
unnamed: Q1.2 (B1), Q1.5 (B2), Q1.6 (C1), R5.2
unnamed: Q1.3 (C2), R13.1
unnamed: Q2.2 (B1), Q2.5 (B2), Q2.6 (C1), R7.2
unnamed: Q2.3 (C2), R14.1
unnamed: Q3.2 (B1), R9.1, R11.1, RV1.3
unnamed: Q3.1 (E1), Q3.4 (E2), R13.2
unnamed: Q3.5 (B2), R19.2, R20.1, RV1.1
unnamed: Q3.3 (C2), R15.1
unnamed: Q4.2 (B1), R10.1, R12.1, RV2.3
unnamed: Q4.1 (E1), Q4.4 (E2), R14.2
unnamed: Q4.5 (B2), R21.2, R22.1, RV2.1
unnamed: Q4.3 (C2), R16.1
unnamed: R6.2, RV1.2
unnamed: R8.2, RV2.2
unnamed: R17.2, RV3.1
unnamed: R18.2, RV4.1
unnamed: R19.1, RV3.2
unnamed: R21.1, RV4.2
unnamed: R23.1, R29.1, U5.1
unnamed: R28.2, R30.1, U5.7
unnamed: C13.1, SW1.2 (3), U1.12, U5.2 (-), U5.5 (+)
unnamed: C15.1, SW1.3 (4)
unnamed: R23.2, R24.1, U1.3 (+), U1.14 (+)
unnamed: R25.2, U1.4 (-), U1.13 (-)
unnamed: J5.T, R4.2, U3.3 (+)
unnamed: R8.1, U3.1, U3.2 (-)
unnamed: J4.T, R3.2, U3.12 (+)
unnamed: R7.1, U3.13 (-), U3.14
unnamed: J3.T, R2.2, U4.3 (+)
unnamed: R6.1, U4.1, U4.2 (-)
unnamed: J2.T, R1.2, U4.12 (+)
unnamed: R5.1, U4.13 (-), U4.14
unnamed: R26.1, U1.5, U5.3 (+)
unnamed: R27.2, R28.1, U5.6 (-)
Square: R29.2; also elsewhere on the board
Triangle: R30.2; also elsewhere on the board

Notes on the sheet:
0.047uF/50V 4.8×3.3×1.5 ECHU1H473GX9
1μF/25V 3.2x1.6x1.4 25MU105MA23216
1000pF/50V 2.0×1.25×0.9 ECHU1H102GX5

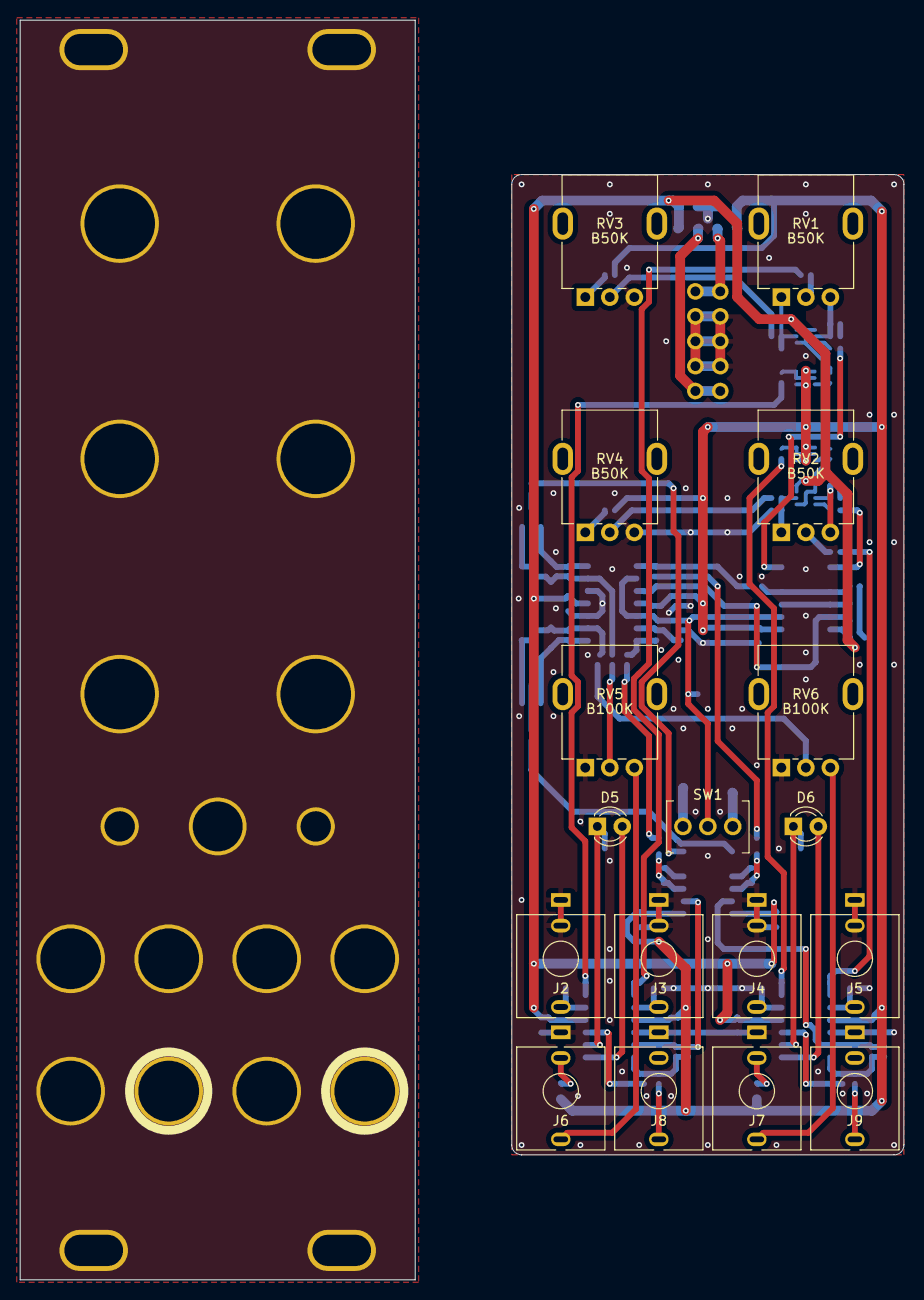
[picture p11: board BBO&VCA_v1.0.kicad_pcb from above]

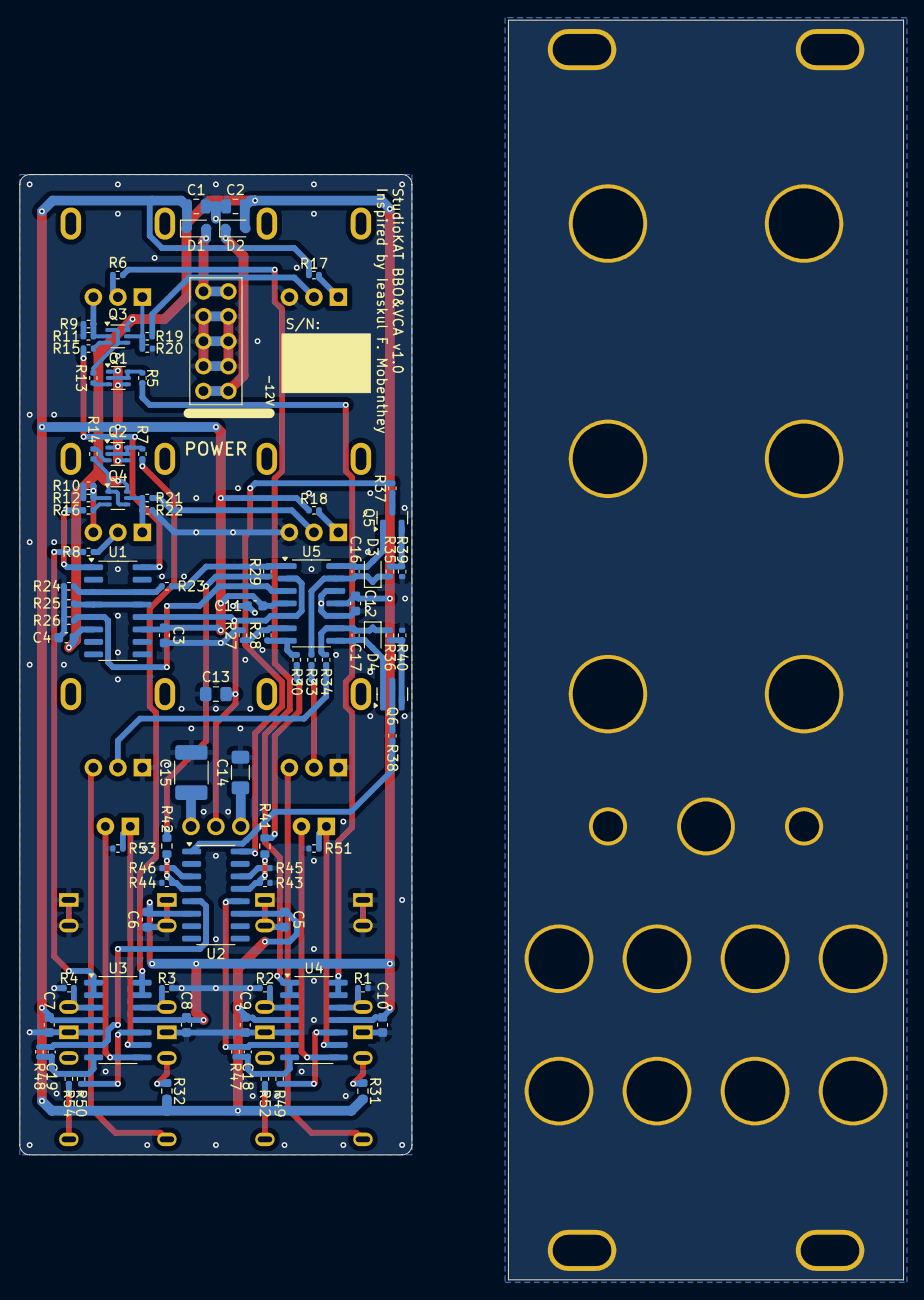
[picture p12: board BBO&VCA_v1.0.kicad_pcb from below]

Board: 2 copper layers, 40.0 x 100.0 mm, 124 parts (89 on the bottom side), 77 nets.

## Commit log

2025-07-16 販売ページURL追加
2025-07-19 消費電力を実測値に変更
